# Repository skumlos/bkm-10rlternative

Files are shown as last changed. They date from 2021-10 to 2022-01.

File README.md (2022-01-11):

BKM-10Rlternative, a plug-and-play replacement for the BKM-10R/11R (except for memory card, for now).

Inspired by Aaron Bonhams BKM-10Rduino, which is genious!

Still early, and there's a LOT of components, plus some tweaks might still be needed: 
* Button RC-filters, as I feel that the 10nF should be replaced with 100nF, but needs testing.
* LED current limiting resistors is of course a preference. I used 470 Ohm in my first prototype.
* UART CTS/RTS pins are sorta irrelevant, as they're set static anyways. Removing these would also free
up pins for porting to regular Atmega328P/Arduino Nano 3.0 board.
* The discrete SS pins for each MCP23S17 should be irrelevant when using multiple addresses (which they
are configured as) so removing them in the future, to free up pins would be an idea.

Plans on memory card stuff for firmware updates and such via SD cards, is planned, at least to be researched.

While the unit is modeled after the BKM-11R, the wiring of the serial port is done like the BKM-10R, meaning
it uses a straight through male-male RS232/DE-9 cable, just like the BKM-10R. It is therefore not compatible
with BKM-11R DE-9 -> mini-DIN cables, unless you make your own.

There is a "classic" IR receiver designed into the PCB. It is unused at the moment, and shouldn't be mounted
before the software actually uses it. It was/is meant to be able to replicate some of the BKM-10Rduino 
functionality at some point, to have an all-in-one unit.

(2022) Martin Hejnfelt, martin@hejnfelt.com

https://www.immerhax.com

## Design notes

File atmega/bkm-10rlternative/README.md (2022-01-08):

BKM-10Rlternative code for Atmega328PB MCU

This code is based on the pastebin of the BKM-10R protocol found here: https://pastebin.com/aTUWf33J

For now I have at least one addition to this, namely that the ICC "bank" seems to be more like an "update me" command
if initiated from the remote, or an "you'd better update" if initiated from the monitor. So if the monitor issues
an ICC message, and the remote replies with this, the monitor gives the LED states back.
Thus this is also initiated by the remote when booted, as the monitor *might* be turned on already when the remote
gets power, and it thus needs to have its LED states updated.

Also the "ticks" of the encoders are kinda weird, it's at least not just "how far the encoder has moved", as that
basically makes turning the knobs min -> max take forever (unless the original encoders have *a lot* of PPRs).
I haven't listened in on the original remote, but I've decided that this "fine tuning" or 
"let's turn that sucker" depending on tick number approach seems to work close to the original.

Easiest way to get this going is to install MiniCore in Arduino IDE.

-----------

I have used a couple of libraries to avoid re-inventing the wheel, so here are some attributions:

Yet Another Arduino PcInt Library (LGPL license):
* PinChangeInterruptBoards.h
* YetAnotherPcInt.cpp
* YetAnotherPcInt.h

Full library here: https://github.com/paulo-raca/YetAnotherArduinoPcIntLibrary 

This is used to control the rotary encoders for pin change interrupts. 
The Atmega328PB is not natively supported by this library, so I've patched it in.

MCP23S17 (Unknown license):
* MCP23S17.cpp
* MCP23S17.h

Full library here: https://github.com/n0mjs710/MCP23S17

This is used to speak with the MCP23S17 SPI I/O expanders. Since I used SPI1, I had to patch this in.

-----------

Suggestions, criticism, takedown notices, etc. go to martin@hejnfelt.com. 

(2022) Martin Hejnfelt, https://www.immerhax.com

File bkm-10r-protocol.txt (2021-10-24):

BKM-10R Protocol
Version 1 - May 16, 2016
License: CC0

The BKM-10R is a remote control used for Sony BVM CRT televisions. It is
required to control some CRTs without built in control, such as the BVM-20F1U.

The protocol is vaguely similar to the one used to control Sony VCRs:
ftp://ftp.sgi.com/sgi/video/rld/vidpage/s9pin.html

This document currently only applies to the CONTROL connection, not to the
REMOTE 1 input/output, though it's expected that they are similar.

== Pinout ==

The remote control and CRT are connected with straight through male-male DE9
cable.

Female DB-9, BKM-10R side:
1. GND
2. /TXD
3. RXD
4. GND
5. +5V
6. GND
7. TXD
8. /RXD
9. GND

Since a straight through cable is used, TXD on the remote side is RXD on the
CRT side. +5V is supplied from the CRT to power the remote.

== Protocol ==

Full duplex RS-422, 38400 baud, 8N1 (the Sony VCR protocol uses odd parity, but
that seems not to be the case here). If you only want to control the CRT,
half duplex RS-485 is electrically compatible.

== Bank ==

There are multiple "banks" that can be switched via 3 byte commands:
0x49 0x45 0x4E - "IEN" - encoders
0x49 0x53 0x57 - "ISW" - switches
0x49 0x4C 0x45 - "ILE" - leds
0x49 0x43 0x43 - "ICC" - ??
0x49 0x4d 0x54 - "IMT" - ??

The remote lazily switches banks when needed.

== Keypresses ==

Each keydown sends 0x44, then group, then mask.
0x44 <group> <mask>

The SHIFT key is "just another key" - state is kept on the CRT. Shifted labels
are listed after non-shifted labels.

You must be in the "ISW" bank first.

<group> <mask> - label
0x03 0x01 - SHIFT
0x03 0x02 - OVERSCAN / 16:9
0x03 0x04 - HORIZ SYNC VIEW / SYNC
0x03 0x08 - VERT SYNC VIEW / BLUE ONLY
0x03 0x10 - MONO / R
0x04 0x01 - APT / G
0x04 0x02 - COMB / B
0x04 0x04 - F1 / F3
0x04 0x08 - F2 / F4
0x04 0x10 - SAFE AREA / ADDRESS
0x02 0x40 - UP
0x02 0x80 - DOWN
0x02 0x10 - MENU
0x02 0x20 - ENTER
0x02 0x08 - PHASE MANUAL
0x02 0x04 - CHROMA MANUAL
0x02 0x02 - BRIGHT MANUAL
0x02 0x01 - CONTRAST MANUAL
0x00 0x01 - 0
0x00 0x02 - 1
0x00 0x04 - 2
0x00 0x08 - 3
0x00 0x10 - 4
0x00 0x20 - 5
0x00 0x40 - 6
0x00 0x80 - 7
0x01 0x01 - 8
0x01 0x02 - 9
0x01 0x04 - Del
0x01 0x08 - Ent
0x01 0x10 - POWER (but see below)
0x01 0x20 - DEGAUSS

== POWER ==

You only need to send a POWER keypress to turn on the monitor, but for some
reason the remote does more.

Power sends five 3-byte sequences:
0x49 0x53 0x57 - switch bank
0x44 0x01 0x10 - POWER switch
(1s pause)
0x49 0x43 0x43 - CC bank?
0x49 0x4d 0x54 - MT bank?
0x44 0x33 0x31 - switch?

CRT responds with:
0x49 0x43 0x43 - CC bank?
<full led state report>
0x49 0x4d 0x54 - MT bank?
<full led state report>

== Encoders ==

Dials are rotary encoders that send 3 bytes:
0x44 <encoder id id> <ticks>

Ticks is a two's complement byte indicating how far the dial has turned since
the last message. The remote sends messages about every 100ms when the dial
is turning.

You must be in the "IEN" bank first.

0x03 - PHASE
0x02 - CHROMA
0x01 - BRIGHT
0x00 - CONTRAST

== LEDs ==

LEDs use the same groups and masks as keypresses. Every time the CRT needs to
change the lights, it changes to the LED bank:

0x49 0x4c 0x45

then sends changed switch groups:

0x44 <group> <mask>

where <mask> is all of the active LED masks OR'd together.

== Memory Card ==

Nobody cares.

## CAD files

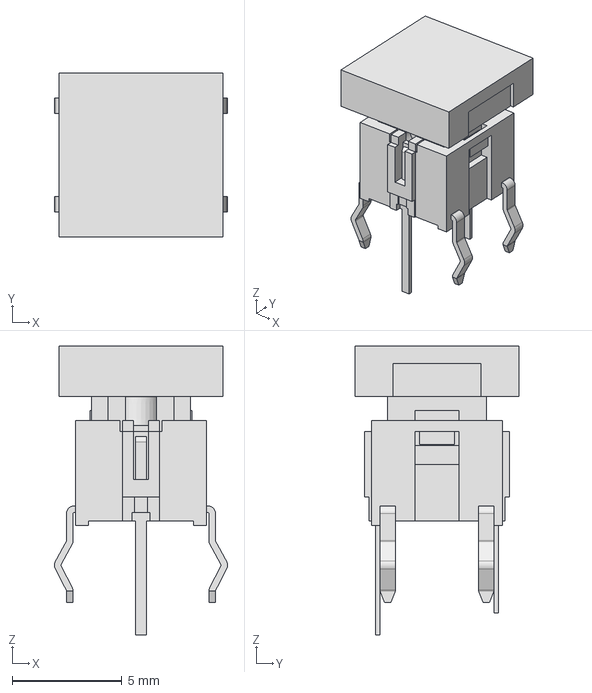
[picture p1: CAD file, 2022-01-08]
TL1240xQ2Jxxx.stp
7.90 x 7.50 x 13.2 mm

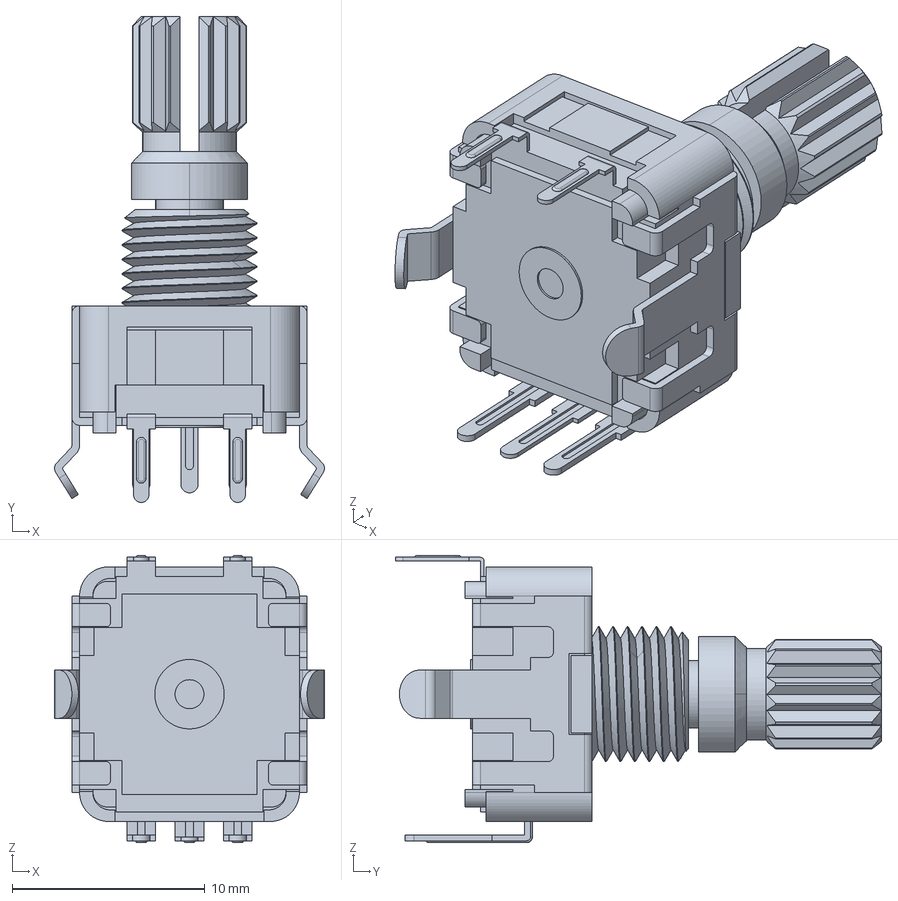
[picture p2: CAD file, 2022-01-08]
pec11r-4x15k-sxxxx.stp
14.0 x 25.2 x 14.9 mm

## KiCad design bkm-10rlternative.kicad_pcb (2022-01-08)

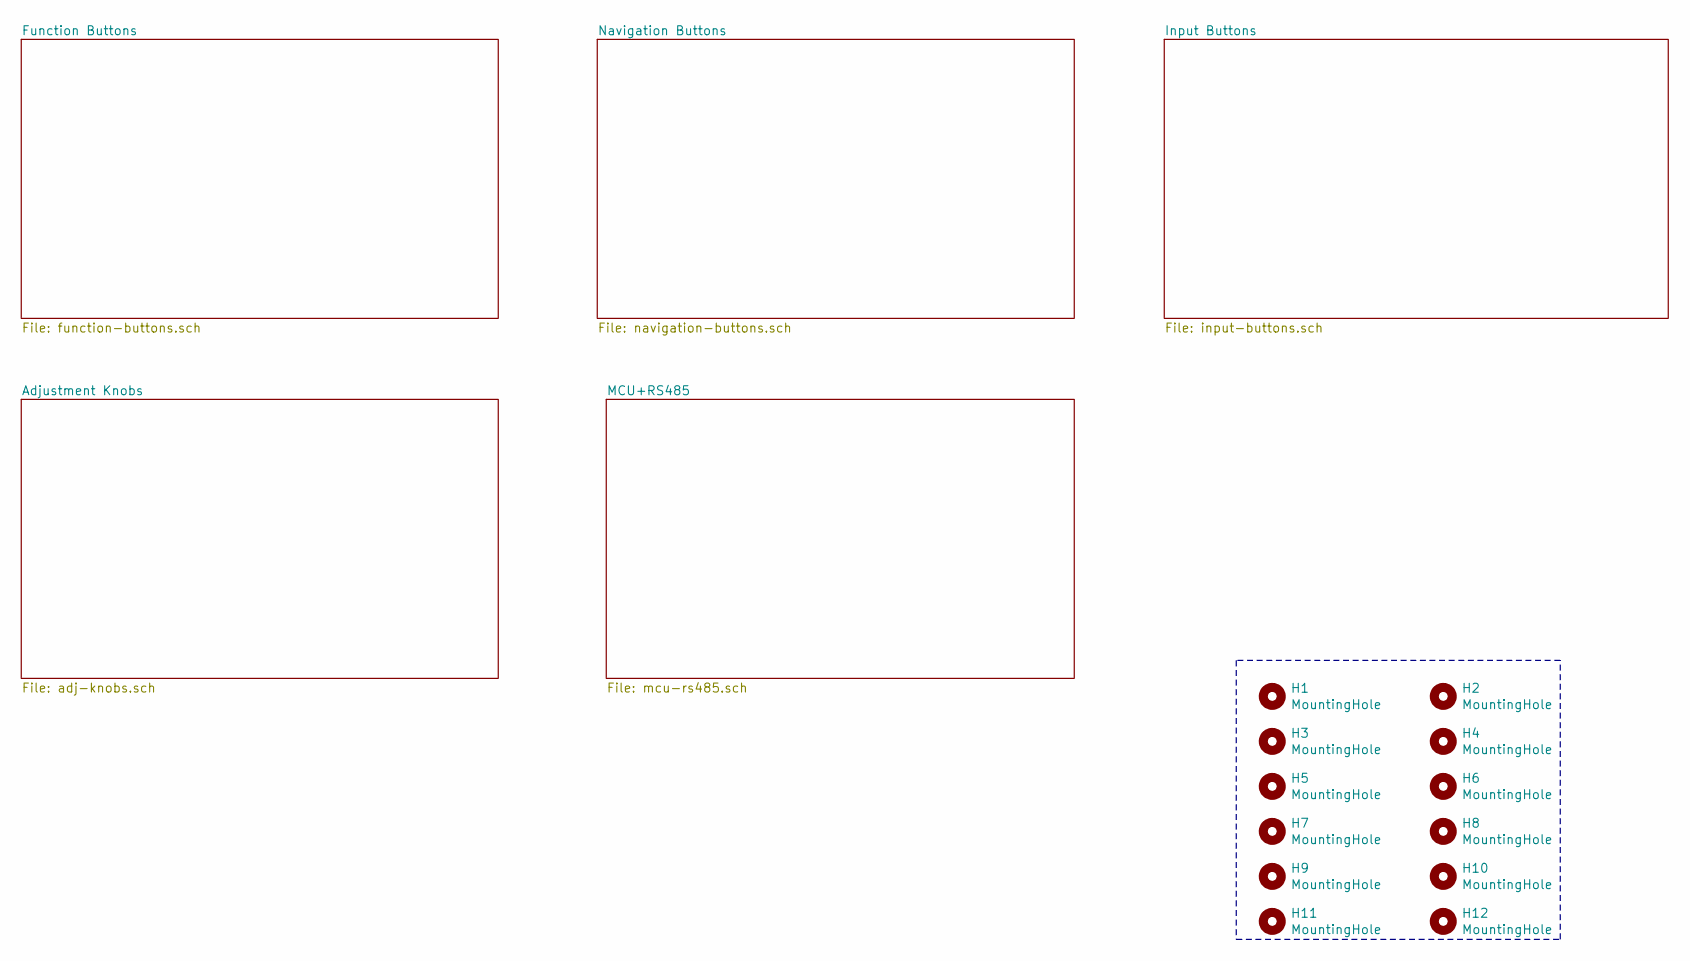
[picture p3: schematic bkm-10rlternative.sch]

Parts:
H1, H2, H3, H4, H5, H6, H7, H8, H9, H10, H11, H12: MountingHole; MountingHole_3.2mm_M3

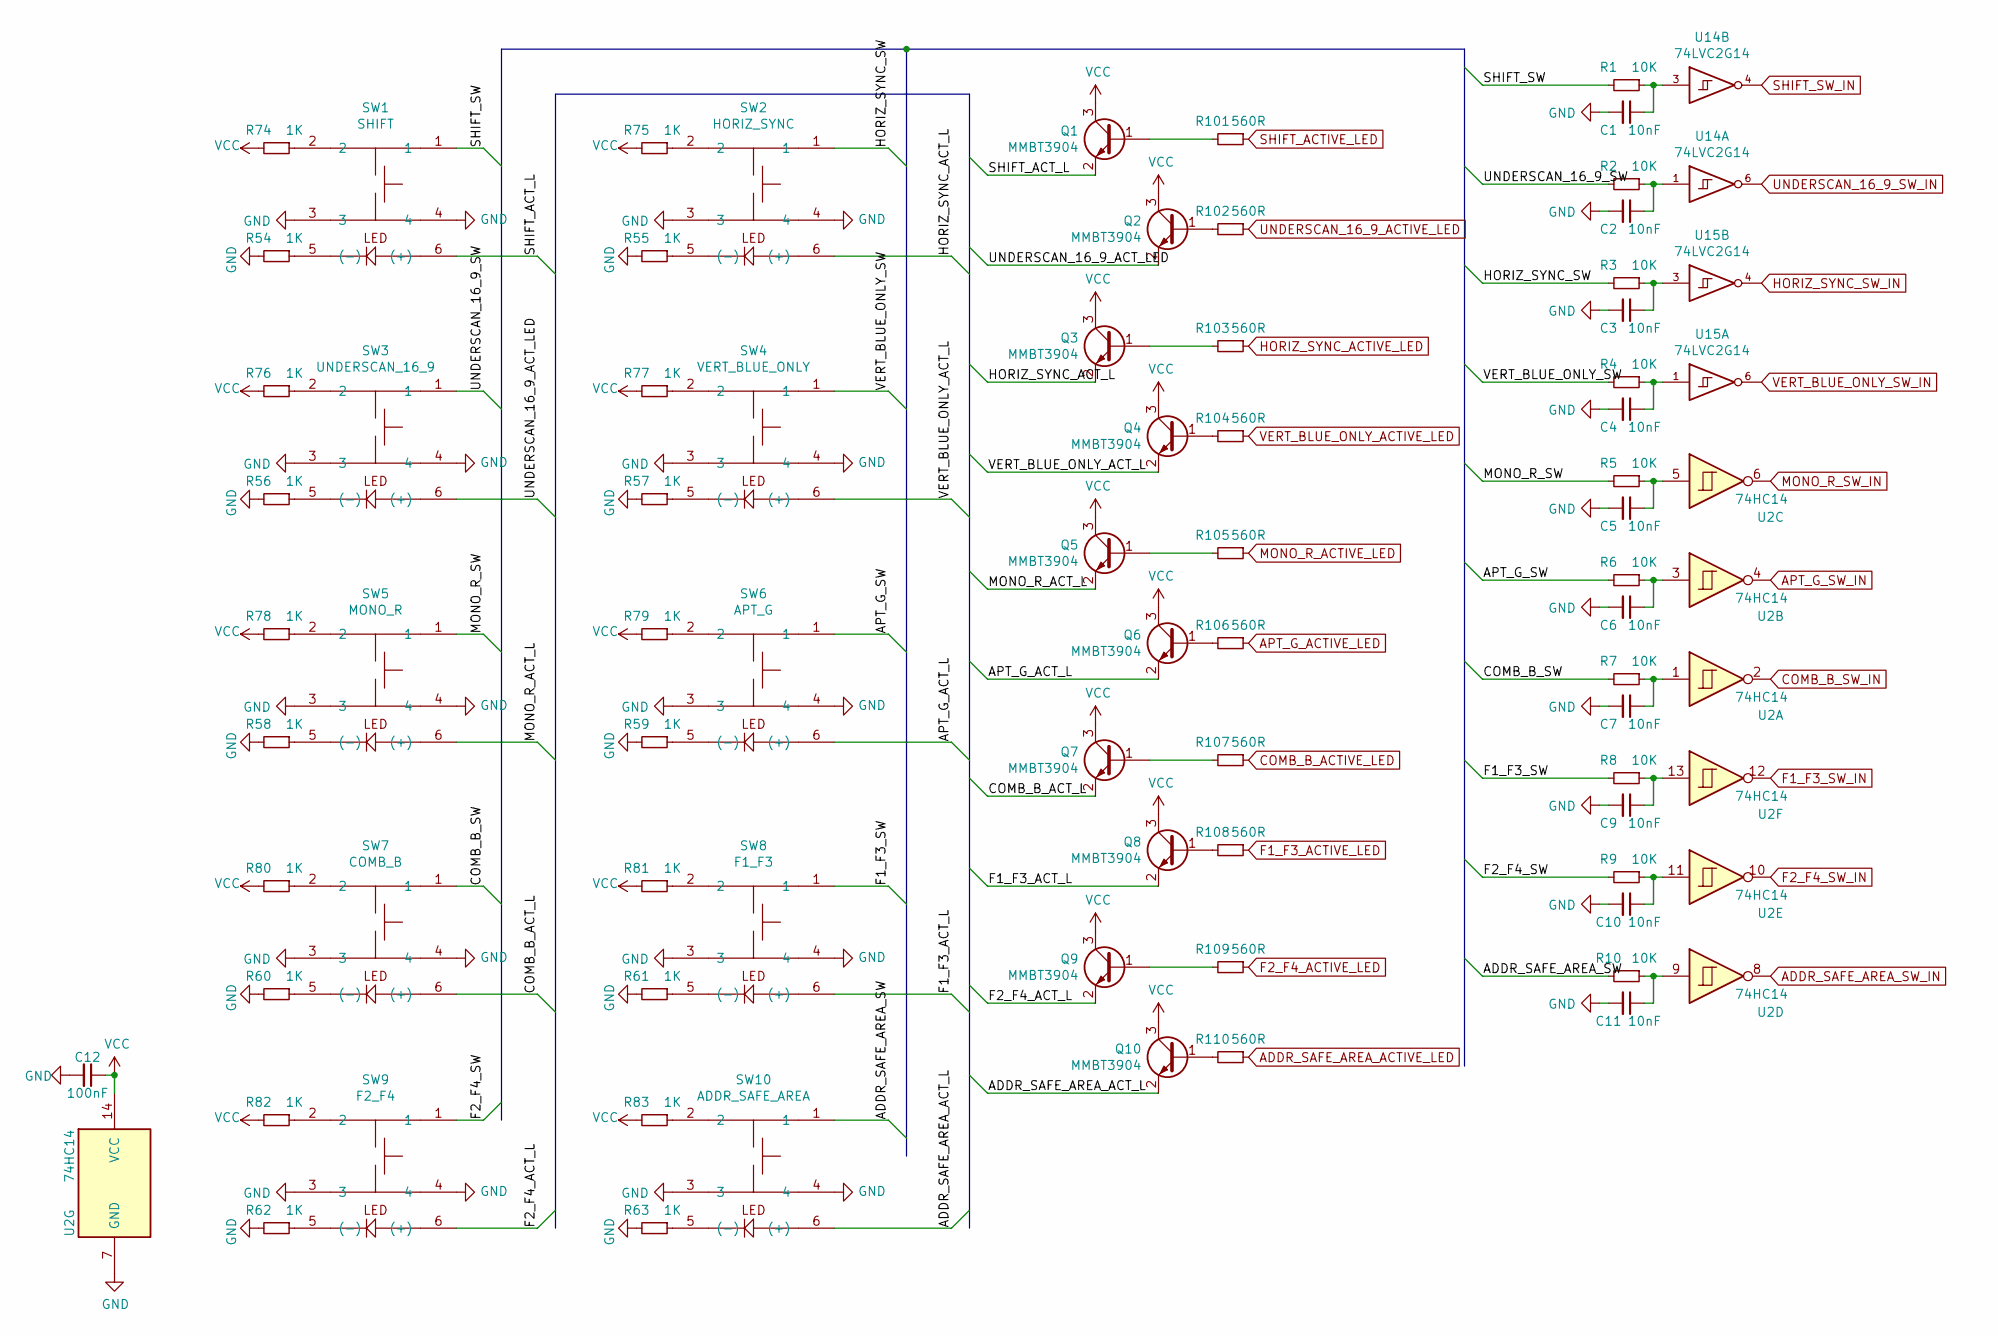
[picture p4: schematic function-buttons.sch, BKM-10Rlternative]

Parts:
C1, C2, C3, C4, C5, C6, C7, C9, C10, C11: 10nF; C_0603_1608Metric_Pad1.08x0.95mm_HandSolder
C12: 100nF; C_0603_1608Metric_Pad1.08x0.95mm_HandSolder
Q1, Q2, Q3, Q4, Q5, Q6, Q7, Q8, Q9, Q10: MMBT3904; SOT-23
R1, R2, R3, R4, R5, R6, R7, R8, R9, R10: 10K; R_0603_1608Metric_Pad0.98x0.95mm_HandSolder
R54, R55, R56, R57, R58, R59, R60, R61, R62, R63, R74, R75, R76, R77, R78, R79, R80, R81, R82, R83: 1K; R_0603_1608Metric_Pad0.98x0.95mm_HandSolder
R101, R102, R103, R104, R105, R106, R107, R108, R109, R110: 560R; R_0603_1608Metric_Pad0.98x0.95mm_HandSolder
SW1: SHIFT; TL-1240
SW2: HORIZ_SYNC; TL-1240
SW3: UNDERSCAN_16_9; TL-1240
SW4: VERT_BLUE_ONLY; TL-1240
SW5: MONO_R; TL-1240
SW6: APT_G; TL-1240
SW7: COMB_B; TL-1240
SW8: F1_F3; TL-1240
SW9: F2_F4; TL-1240
SW10: ADDR_SAFE_AREA; TL-1240
U2: 74HC14; SSOP-14_5.3x6.2mm_P0.65mm
U14, U15: 74LVC2G14; SOT-23-6_Handsoldering

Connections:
/Function Buttons/ADDR_SAFE_AREA_ACT_L: Q10.2 (E), SW10.6 ((+))
/Function Buttons/ADDR_SAFE_AREA_SW: R10.2, SW10.1
/Function Buttons/APT_G_ACT_L: Q6.2 (E), SW6.6 ((+))
/Function Buttons/APT_G_SW: R6.2, SW6.1
/Function Buttons/COMB_B_ACT_L: Q7.2 (E), SW7.6 ((+))
/Function Buttons/COMB_B_SW: R7.2, SW7.1
/Function Buttons/F1_F3_ACT_L: Q8.2 (E), SW8.6 ((+))
/Function Buttons/F1_F3_SW: R8.2, SW8.1
/Function Buttons/F2_F4_ACT_L: Q9.2 (E), SW9.6 ((+))
/Function Buttons/F2_F4_SW: R9.2, SW9.1
/Function Buttons/HORIZ_SYNC_ACT_L: Q3.2 (E), SW2.6 ((+))
/Function Buttons/HORIZ_SYNC_SW: R3.2, SW2.1
/Function Buttons/MONO_R_ACT_L: Q5.2 (E), SW5.6 ((+))
/Function Buttons/MONO_R_SW: R5.2, SW5.1
/Function Buttons/SHIFT_ACT_L: Q1.2 (E), SW1.6 ((+))
/Function Buttons/SHIFT_SW: R1.2, SW1.1
/Function Buttons/UNDERSCAN_16_9_ACT_LED: Q2.2 (E), SW3.6 ((+))
/Function Buttons/UNDERSCAN_16_9_SW: R2.2, SW3.1
/Function Buttons/VERT_BLUE_ONLY_ACT_L: Q4.2 (E), SW4.6 ((+))
/Function Buttons/VERT_BLUE_ONLY_SW: R4.2, SW4.1
ADDR_SAFE_AREA_ACTIVE_LED: R110.1; also elsewhere on the board
ADDR_SAFE_AREA_SW_IN: U2.8; also elsewhere on the board
APT_G_ACTIVE_LED: R106.1; also elsewhere on the board
APT_G_SW_IN: U2.4; also elsewhere on the board
COMB_B_ACTIVE_LED: R107.1; also elsewhere on the board
COMB_B_SW_IN: U2.2; also elsewhere on the board
F1_F3_ACTIVE_LED: R108.1; also elsewhere on the board
F1_F3_SW_IN: U2.12; also elsewhere on the board
F2_F4_ACTIVE_LED: R109.1; also elsewhere on the board
F2_F4_SW_IN: U2.10; also elsewhere on the board
GND: C1.2, C2.2, C3.2, C4.2, C5.2, C6.2, C7.2, C9.2, C10.2, C11.2, C12.2, R54.2, R55.2, R56.2, R57.2, R58.2, R59.2, R60.2, R61.2, R62.2, R63.2, SW1.3, SW1.4, SW2.3, SW2.4, SW3.3, SW3.4, SW4.3, SW4.4, SW5.3, SW5.4, SW6.3, SW6.4, SW7.3, SW7.4, SW8.3, SW8.4, SW9.3, SW9.4, SW10.3, SW10.4, U2.7 (GND), U14.2 (GND), U15.2 (GND); also elsewhere on the board
HORIZ_SYNC_ACTIVE_LED: R103.1; also elsewhere on the board
HORIZ_SYNC_SW_IN: U15.4; also elsewhere on the board
MONO_R_ACTIVE_LED: R105.1; also elsewhere on the board
MONO_R_SW_IN: U2.6; also elsewhere on the board
unnamed: C1.1, R1.1, U14.3
unnamed: C2.1, R2.1, U14.1
unnamed: C3.1, R3.1, U15.3
unnamed: C4.1, R4.1, U15.1
unnamed: C5.1, R5.1, U2.5
unnamed: C6.1, R6.1, U2.3
unnamed: C7.1, R7.1, U2.1
unnamed: C9.1, R8.1, U2.13
unnamed: C10.1, R9.1, U2.11
unnamed: C11.1, R10.1, U2.9
unnamed: Q1.1 (B), R101.2
unnamed: Q2.1 (B), R102.2
unnamed: Q3.1 (B), R103.2
unnamed: Q4.1 (B), R104.2
unnamed: Q5.1 (B), R105.2
unnamed: Q6.1 (B), R106.2
unnamed: Q7.1 (B), R107.2
unnamed: Q8.1 (B), R108.2
unnamed: Q9.1 (B), R109.2
unnamed: Q10.1 (B), R110.2
unnamed: R54.1, SW1.5 ((-))
unnamed: R55.1, SW2.5 ((-))
unnamed: R56.1, SW3.5 ((-))
unnamed: R57.1, SW4.5 ((-))
unnamed: R58.1, SW5.5 ((-))
unnamed: R59.1, SW6.5 ((-))
unnamed: R60.1, SW7.5 ((-))
unnamed: R61.1, SW8.5 ((-))
unnamed: R62.1, SW9.5 ((-))
unnamed: R63.1, SW10.5 ((-))
unnamed: R74.1, SW1.2
unnamed: R75.1, SW2.2
unnamed: R76.1, SW3.2
unnamed: R77.1, SW4.2
unnamed: R78.1, SW5.2
unnamed: R79.1, SW6.2
unnamed: R80.1, SW7.2
unnamed: R81.1, SW8.2
unnamed: R82.1, SW9.2
unnamed: R83.1, SW10.2
SHIFT_ACTIVE_LED: R101.1; also elsewhere on the board
SHIFT_SW_IN: U14.4; also elsewhere on the board
UNDERSCAN_16_9_ACTIVE_LED: R102.1; also elsewhere on the board
UNDERSCAN_16_9_SW_IN: U14.6; also elsewhere on the board
VCC: C12.1, Q1.3 (C), Q2.3 (C), Q3.3 (C), Q4.3 (C), Q5.3 (C), Q6.3 (C), Q7.3 (C), Q8.3 (C), Q9.3 (C), Q10.3 (C), R74.2, R75.2, R76.2, R77.2, R78.2, R79.2, R80.2, R81.2, R82.2, R83.2, U2.14 (VCC), U14.5 (VCC), U15.5 (VCC); also elsewhere on the board
VERT_BLUE_ONLY_ACTIVE_LED: R104.1; also elsewhere on the board
VERT_BLUE_ONLY_SW_IN: U15.6; also elsewhere on the board

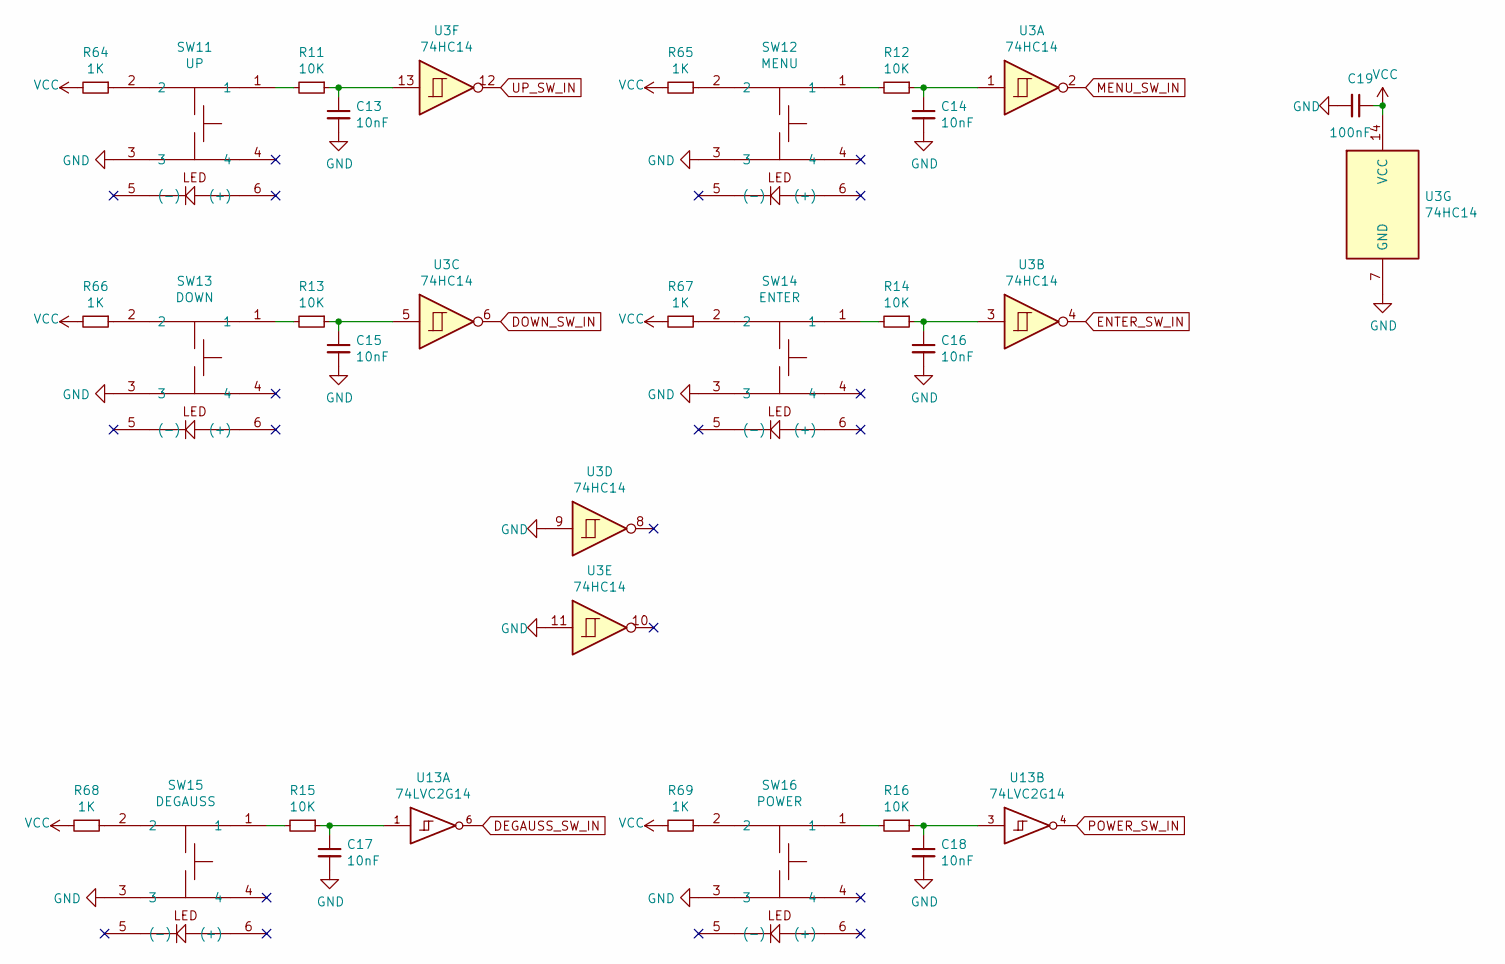
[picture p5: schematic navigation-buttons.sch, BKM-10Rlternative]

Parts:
C13, C14, C15, C16, C17, C18: 10nF; C_0603_1608Metric_Pad1.08x0.95mm_HandSolder
C19: 100nF; C_0603_1608Metric_Pad1.08x0.95mm_HandSolder
R11, R12, R13, R14, R15, R16: 10K; R_0603_1608Metric_Pad0.98x0.95mm_HandSolder
R64, R65, R66, R67, R68, R69: 1K; R_0603_1608Metric_Pad0.98x0.95mm_HandSolder
SW11: UP; TL-1240
SW12: MENU; TL-1240
SW13: DOWN; TL-1240
SW14: ENTER; TL-1240
SW15: DEGAUSS; TL-1240
SW16: POWER; TL-1240
U3: 74HC14; SSOP-14_5.3x6.2mm_P0.65mm
U13: 74LVC2G14; SOT-23-6_Handsoldering

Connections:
DEGAUSS_SW_IN: U13.6; also elsewhere on the board
DOWN_SW_IN: U3.6; also elsewhere on the board
ENTER_SW_IN: U3.4; also elsewhere on the board
GND: C13.2, C14.2, C15.2, C16.2, C17.2, C18.2, C19.2, SW11.3, SW12.3, SW13.3, SW14.3, SW15.3, SW16.3, U3.7 (GND), U3.9, U3.11, U13.2 (GND); also elsewhere on the board
MENU_SW_IN: U3.2; also elsewhere on the board
unnamed: C13.1, R11.1, U3.13
unnamed: C14.1, R12.1, U3.1
unnamed: C15.1, R13.1, U3.5
unnamed: C16.1, R14.1, U3.3
unnamed: C17.1, R15.1, U13.1
unnamed: C18.1, R16.1, U13.3
unnamed: R11.2, SW11.1
unnamed: R12.2, SW12.1
unnamed: R13.2, SW13.1
unnamed: R14.2, SW14.1
unnamed: R15.2, SW15.1
unnamed: R16.2, SW16.1
unnamed: R64.1, SW11.2
unnamed: R65.1, SW12.2
unnamed: R66.1, SW13.2
unnamed: R67.1, SW14.2
unnamed: R68.1, SW15.2
unnamed: R69.1, SW16.2
POWER_SW_IN: U13.4; also elsewhere on the board
UP_SW_IN: U3.12; also elsewhere on the board
VCC: C19.1, R64.2, R65.2, R66.2, R67.2, R68.2, R69.2, U3.14 (VCC), U13.5 (VCC); also elsewhere on the board

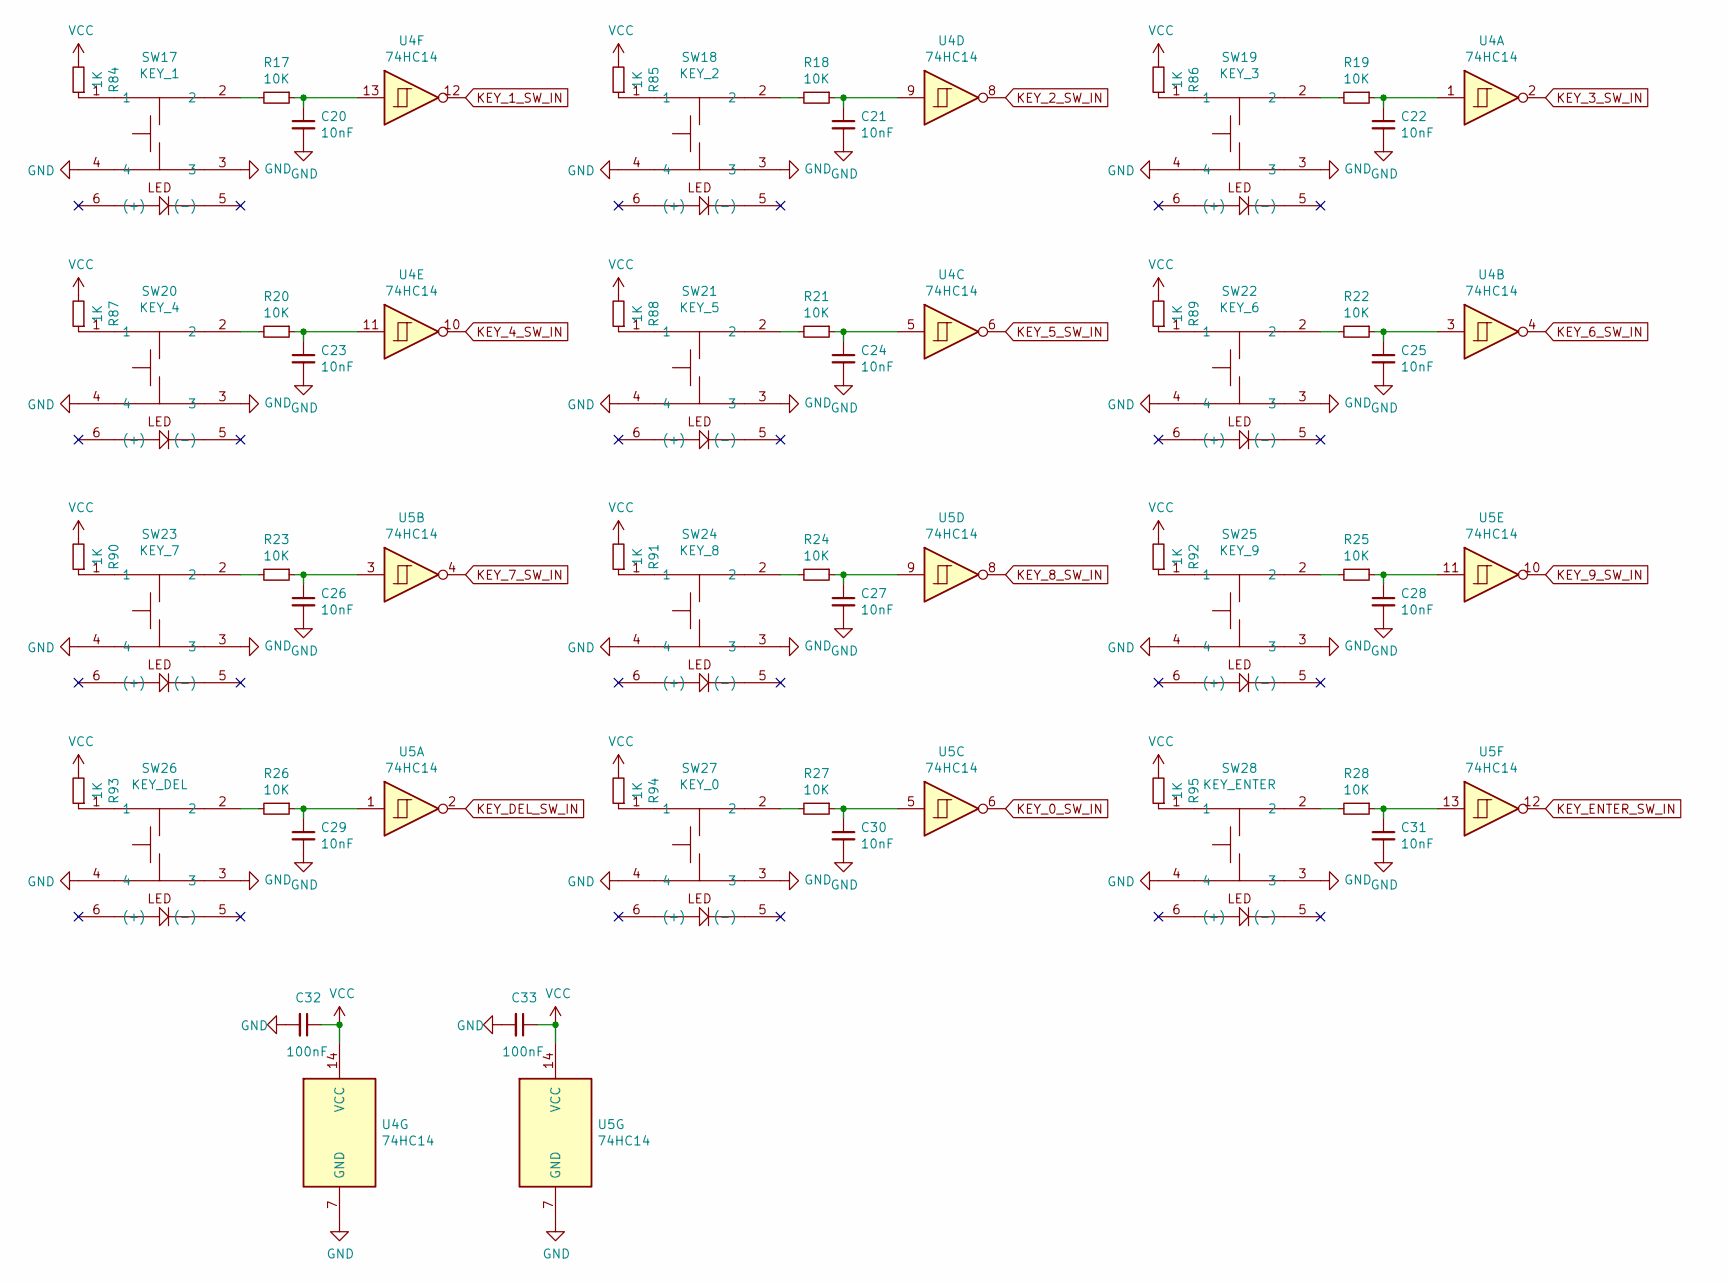
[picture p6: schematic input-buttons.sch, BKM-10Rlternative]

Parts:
C20, C21, C22, C23, C24, C25, C26, C27, C28, C29, C30, C31: 10nF; C_0603_1608Metric_Pad1.08x0.95mm_HandSolder
C32, C33: 100nF; C_0603_1608Metric_Pad1.08x0.95mm_HandSolder
R17, R18, R19, R20, R21, R22, R23, R24, R25, R26, R27, R28: 10K; R_0603_1608Metric_Pad0.98x0.95mm_HandSolder
R84, R85, R86, R87, R88, R89, R90, R91, R92, R93, R94, R95: 1K; R_0603_1608Metric_Pad0.98x0.95mm_HandSolder
SW17: KEY_1; TL-1240
SW18: KEY_2; TL-1240
SW19: KEY_3; TL-1240
SW20: KEY_4; TL-1240
SW21: KEY_5; TL-1240
SW22: KEY_6; TL-1240
SW23: KEY_7; TL-1240
SW24: KEY_8; TL-1240
SW25: KEY_9; TL-1240
SW26: KEY_DEL; TL-1240
SW27: KEY_0; TL-1240
SW28: KEY_ENTER; TL-1240
U4, U5: 74HC14; SSOP-14_5.3x6.2mm_P0.65mm

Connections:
GND: C20.2, C21.2, C22.2, C23.2, C24.2, C25.2, C26.2, C27.2, C28.2, C29.2, C30.2, C31.2, C32.2, C33.2, SW17.3, SW17.4, SW18.3, SW18.4, SW19.3, SW19.4, SW20.3, SW20.4, SW21.3, SW21.4, SW22.3, SW22.4, SW23.3, SW23.4, SW24.3, SW24.4, SW25.3, SW25.4, SW26.3, SW26.4, SW27.3, SW27.4, SW28.3, SW28.4, U4.7 (GND), U5.7 (GND); also elsewhere on the board
KEY_0_SW_IN: U5.6; also elsewhere on the board
KEY_1_SW_IN: U4.12; also elsewhere on the board
KEY_2_SW_IN: U4.8; also elsewhere on the board
KEY_3_SW_IN: U4.2; also elsewhere on the board
KEY_4_SW_IN: U4.10; also elsewhere on the board
KEY_5_SW_IN: U4.6; also elsewhere on the board
KEY_6_SW_IN: U4.4; also elsewhere on the board
KEY_7_SW_IN: U5.4; also elsewhere on the board
KEY_8_SW_IN: U5.8; also elsewhere on the board
KEY_9_SW_IN: U5.10; also elsewhere on the board
KEY_DEL_SW_IN: U5.2; also elsewhere on the board
KEY_ENTER_SW_IN: U5.12; also elsewhere on the board
unnamed: C20.1, R17.1, U4.13
unnamed: C21.1, R18.1, U4.9
unnamed: C22.1, R19.1, U4.1
unnamed: C23.1, R20.1, U4.11
unnamed: C24.1, R21.1, U4.5
unnamed: C25.1, R22.1, U4.3
unnamed: C26.1, R23.1, U5.3
unnamed: C27.1, R24.1, U5.9
unnamed: C28.1, R25.1, U5.11
unnamed: C29.1, R26.1, U5.1
unnamed: C30.1, R27.1, U5.5
unnamed: C31.1, R28.1, U5.13
unnamed: R17.2, SW17.2
unnamed: R18.2, SW18.2
unnamed: R19.2, SW19.2
unnamed: R20.2, SW20.2
unnamed: R21.2, SW21.2
unnamed: R22.2, SW22.2
unnamed: R23.2, SW23.2
unnamed: R24.2, SW24.2
unnamed: R25.2, SW25.2
unnamed: R26.2, SW26.2
unnamed: R27.2, SW27.2
unnamed: R28.2, SW28.2
unnamed: R84.1, SW17.1
unnamed: R85.1, SW18.1
unnamed: R86.1, SW19.1
unnamed: R87.1, SW20.1
unnamed: R88.1, SW21.1
unnamed: R89.1, SW22.1
unnamed: R90.1, SW23.1
unnamed: R91.1, SW24.1
unnamed: R92.1, SW25.1
unnamed: R93.1, SW26.1
unnamed: R94.1, SW27.1
unnamed: R95.1, SW28.1
VCC: C32.1, C33.1, R84.2, R85.2, R86.2, R87.2, R88.2, R89.2, R90.2, R91.2, R92.2, R93.2, R94.2, R95.2, U4.14 (VCC), U5.14 (VCC); also elsewhere on the board

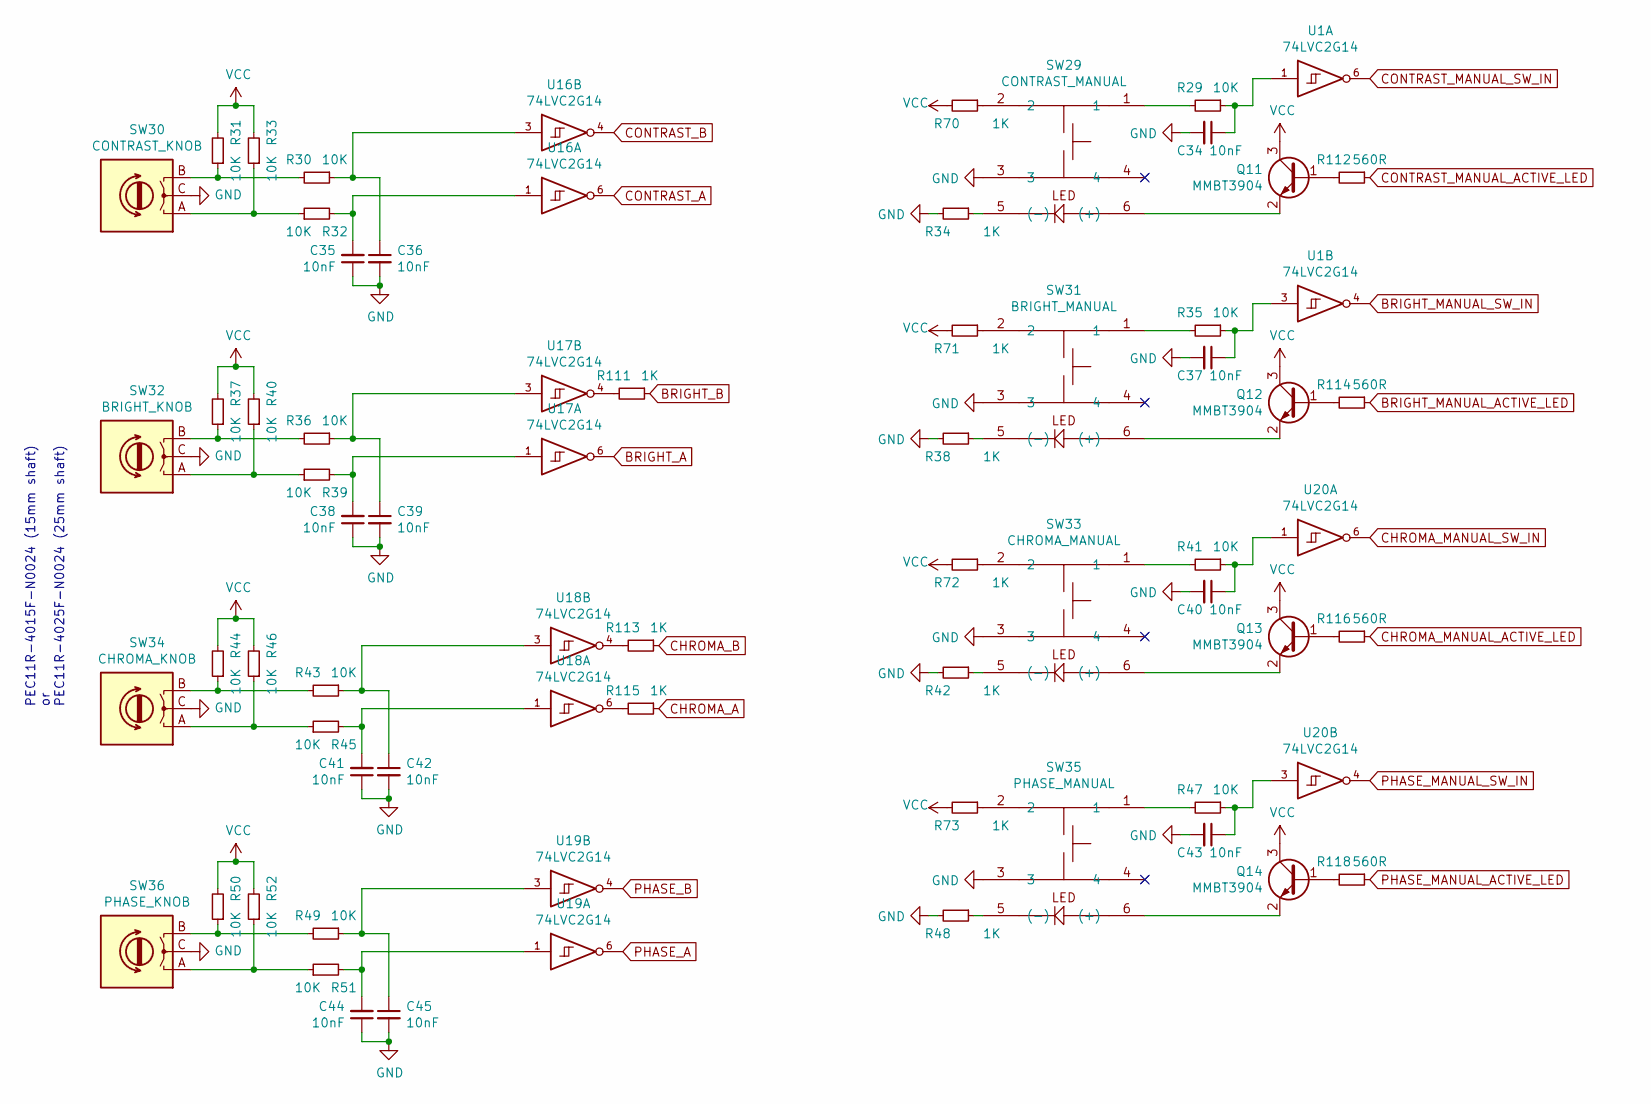
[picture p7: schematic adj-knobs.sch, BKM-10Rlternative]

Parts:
C34, C35, C36, C37, C38, C39, C40, C41, C42, C43, C44, C45: 10nF; C_0603_1608Metric_Pad1.08x0.95mm_HandSolder
Q11, Q12, Q13, Q14: MMBT3904; SOT-23
R29, R30, R31, R32, R33, R35, R36, R37, R39, R40, R41, R43, R44, R45, R46, R47, R49, R50, R51, R52: 10K; R_0603_1608Metric_Pad0.98x0.95mm_HandSolder
R34, R38, R42, R48, R70, R71, R72, R73, R111, R113, R115: 1K; R_0603_1608Metric_Pad0.98x0.95mm_HandSolder
R112, R114, R116, R118: 560R; R_0603_1608Metric_Pad0.98x0.95mm_HandSolder
SW29: CONTRAST_MANUAL; TL-1240
SW30: CONTRAST_KNOB; RotaryEncoder_Alps_EC11E_Vertical_H20mm
SW31: BRIGHT_MANUAL; TL-1240
SW32: BRIGHT_KNOB; RotaryEncoder_Alps_EC11E_Vertical_H20mm
SW33: CHROMA_MANUAL; TL-1240
SW34: CHROMA_KNOB; RotaryEncoder_Alps_EC11E_Vertical_H20mm
SW35: PHASE_MANUAL; TL-1240
SW36: PHASE_KNOB; RotaryEncoder_Alps_EC11E_Vertical_H20mm
U1, U16, U17, U18, U19, U20: 74LVC2G14; SOT-23-6_Handsoldering

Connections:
BRIGHT_A: U17.6; also elsewhere on the board
BRIGHT_B: R111.1; also elsewhere on the board
BRIGHT_MANUAL_ACTIVE_LED: R114.1; also elsewhere on the board
BRIGHT_MANUAL_SW_IN: U1.4; also elsewhere on the board
CHROMA_A: R115.1; also elsewhere on the board
CHROMA_B: R113.1; also elsewhere on the board
CHROMA_MANUAL_ACTIVE_LED: R116.1; also elsewhere on the board
CHROMA_MANUAL_SW_IN: U20.6; also elsewhere on the board
CONTRAST_A: U16.6; also elsewhere on the board
CONTRAST_B: U16.4; also elsewhere on the board
CONTRAST_MANUAL_ACTIVE_LED: R112.1; also elsewhere on the board
CONTRAST_MANUAL_SW_IN: U1.6; also elsewhere on the board
GND: C34.2, C35.1, C36.2, C37.2, C38.1, C39.2, C40.2, C41.1, C42.2, C43.2, C44.1, C45.2, R34.2, R38.2, R42.2, R48.2, SW29.3, SW30.C, SW31.3, SW32.C, SW33.3, SW34.C, SW35.3, SW36.C, U1.2 (GND), U16.2 (GND), U17.2 (GND), U18.2 (GND), U19.2 (GND), U20.2 (GND); also elsewhere on the board
unnamed: C34.1, R29.1, U1.1
unnamed: C35.2, R32.2, U16.1
unnamed: C36.1, R30.1, U16.3
unnamed: C37.1, R35.1, U1.3
unnamed: C38.2, R39.2, U17.1
unnamed: C39.1, R36.1, U17.3
unnamed: C40.1, R41.1, U20.1
unnamed: C41.2, R45.2, U18.1
unnamed: C42.1, R43.1, U18.3
unnamed: C43.1, R47.1, U20.3
unnamed: C44.2, R51.2, U19.1
unnamed: C45.1, R49.1, U19.3
unnamed: Q11.1 (B), R112.2
unnamed: Q11.2 (E), SW29.6 ((+))
unnamed: Q12.1 (B), R114.2
unnamed: Q12.2 (E), SW31.6 ((+))
unnamed: Q13.1 (B), R116.2
unnamed: Q13.2 (E), SW33.6 ((+))
unnamed: Q14.1 (B), R118.2
unnamed: Q14.2 (E), SW35.6 ((+))
unnamed: R29.2, SW29.1
unnamed: R30.2, R31.1, SW30.B
unnamed: R32.1, R33.1, SW30.A
unnamed: R34.1, SW29.5 ((-))
unnamed: R35.2, SW31.1
unnamed: R36.2, R37.1, SW32.B
unnamed: R38.1, SW31.5 ((-))
unnamed: R39.1, R40.1, SW32.A
unnamed: R41.2, SW33.1
unnamed: R42.1, SW33.5 ((-))
unnamed: R43.2, R44.1, SW34.B
unnamed: R45.1, R46.1, SW34.A
unnamed: R47.2, SW35.1
unnamed: R48.1, SW35.5 ((-))
unnamed: R49.2, R50.1, SW36.B
unnamed: R51.1, R52.1, SW36.A
unnamed: R70.1, SW29.2
unnamed: R71.1, SW31.2
unnamed: R72.1, SW33.2
unnamed: R73.1, SW35.2
unnamed: R111.2, U17.4
unnamed: R113.2, U18.4
unnamed: R115.2, U18.6
PHASE_A: U19.6; also elsewhere on the board
PHASE_B: U19.4; also elsewhere on the board
PHASE_MANUAL_ACTIVE_LED: R118.1; also elsewhere on the board
PHASE_MANUAL_SW_IN: U20.4; also elsewhere on the board
VCC: Q11.3 (C), Q12.3 (C), Q13.3 (C), Q14.3 (C), R31.2, R33.2, R37.2, R40.2, R44.2, R46.2, R50.2, R52.2, R70.2, R71.2, R72.2, R73.2, U1.5 (VCC), U16.5 (VCC), U17.5 (VCC), U18.5 (VCC), U19.5 (VCC), U20.5 (VCC); also elsewhere on the board

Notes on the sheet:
PEC11R-4015F-N0024 (15mm shaft) or PEC11R-4025F-N0024 (25mm shaft)

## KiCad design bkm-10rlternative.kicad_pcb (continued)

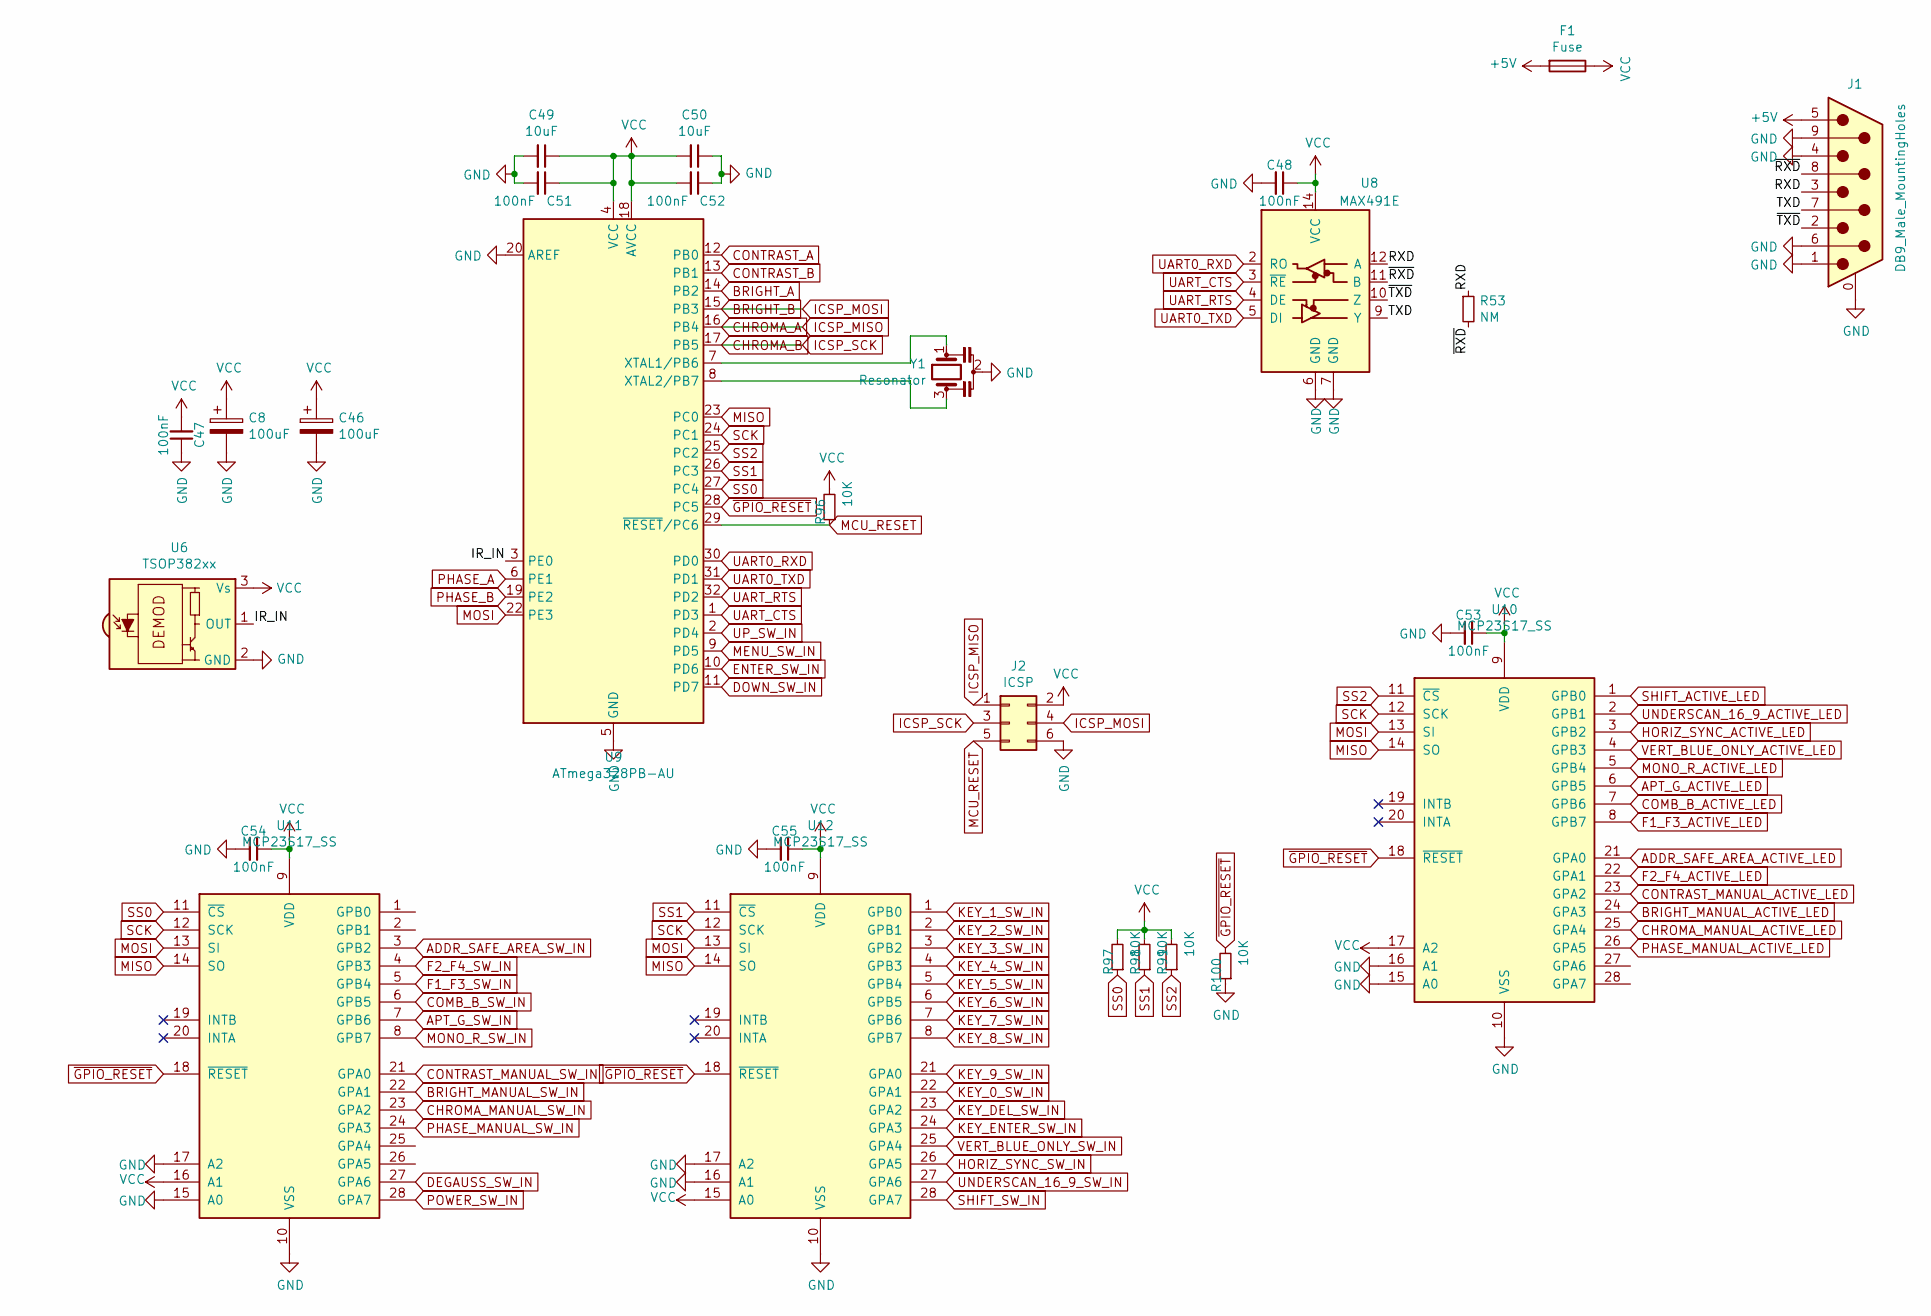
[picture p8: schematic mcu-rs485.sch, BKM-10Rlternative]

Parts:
C8, C46: 100uF; CP_Elec_6.3x5.4
C47, C48, C51, C52, C53, C54, C55: 100nF; C_0603_1608Metric_Pad1.08x0.95mm_HandSolder
C49, C50: 10uF; C_0805_2012Metric_Pad1.18x1.45mm_HandSolder
F1: Fuse; Fuse_1206_3216Metric_Pad1.42x1.75mm_HandSolder
J1: DB9_Male_MountingHoles; DSUB-9_Female_Horizontal_P2.77x2.84mm_EdgePinOffset7.70mm_H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
J2: ICSP; PinHeader_2x03_P2.54mm_Vertical
R53: NM; R_0603_1608Metric_Pad0.98x0.95mm_HandSolder
R96, R97, R98, R99, R100: 10K; R_0603_1608Metric_Pad0.98x0.95mm_HandSolder
U6: TSOP382xx; Vishay_MINICAST-3Pin
U8: MAX491E; SOIC-14_3.9x8.7mm_P1.27mm
U9: ATmega328PB-AU; TQFP-32_7x7mm_P0.8mm
U10, U11, U12: MCP23S17_SS; SSOP-28_5.3x10.2mm_P0.65mm
Y1: Resonator; Resonator_SMD_muRata_CSTxExxV-3Pin_3.0x1.1mm_HandSoldering

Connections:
+5V: F1.2, J1.5
/MCU+RS485/IR_IN: U6.1 (OUT), U9.3 (PE0)
/MCU+RS485/RXD: J1.3, R53.1, U8.12 (A)
/MCU+RS485/TXD: J1.7, U8.9 (Y)
/MCU+RS485/~RXD: J1.8, R53.2, U8.11 (B)
/MCU+RS485/~TXD: J1.2, U8.10 (Z)
ADDR_SAFE_AREA_ACTIVE_LED: U10.21 (GPA0); also elsewhere on the board
ADDR_SAFE_AREA_SW_IN: U11.3 (GPB2); also elsewhere on the board
APT_G_ACTIVE_LED: U10.6 (GPB5); also elsewhere on the board
APT_G_SW_IN: U11.7 (GPB6); also elsewhere on the board
BRIGHT_A: U9.14 (PB2); also elsewhere on the board
BRIGHT_B: J2.4, U9.15 (PB3); also elsewhere on the board
BRIGHT_MANUAL_ACTIVE_LED: U10.24 (GPA3); also elsewhere on the board
BRIGHT_MANUAL_SW_IN: U11.22 (GPA1); also elsewhere on the board
CHROMA_A: J2.1, U9.16 (PB4); also elsewhere on the board
CHROMA_B: J2.3, U9.17 (PB5); also elsewhere on the board
CHROMA_MANUAL_ACTIVE_LED: U10.25 (GPA4); also elsewhere on the board
CHROMA_MANUAL_SW_IN: U11.23 (GPA2); also elsewhere on the board
COMB_B_ACTIVE_LED: U10.7 (GPB6); also elsewhere on the board
COMB_B_SW_IN: U11.6 (GPB5); also elsewhere on the board
CONTRAST_A: U9.12 (PB0); also elsewhere on the board
CONTRAST_B: U9.13 (PB1); also elsewhere on the board
CONTRAST_MANUAL_ACTIVE_LED: U10.23 (GPA2); also elsewhere on the board
CONTRAST_MANUAL_SW_IN: U11.21 (GPA0); also elsewhere on the board
DEGAUSS_SW_IN: U11.27 (GPA6); also elsewhere on the board
DOWN_SW_IN: U9.11 (PD7); also elsewhere on the board
ENTER_SW_IN: U9.10 (PD6); also elsewhere on the board
F1_F3_ACTIVE_LED: U10.8 (GPB7); also elsewhere on the board
F1_F3_SW_IN: U11.5 (GPB4); also elsewhere on the board
F2_F4_ACTIVE_LED: U10.22 (GPA1); also elsewhere on the board
F2_F4_SW_IN: U11.4 (GPB3); also elsewhere on the board
GND: C8.2, C46.2, C47.1, C48.2, C49.2, C50.1, C51.2, C52.1, C53.2, C54.2, C55.2, J1.0 (PAD), J1.1, J1.4, J1.6, J1.9, J2.6, R100.1, U6.2 (GND), U8.6 (GND), U8.7 (GND), U9.5 (GND), U9.20 (AREF), U9.21 (GND), U10.10 (VSS), U10.15 (A0), U10.16 (A1), U11.10 (VSS), U11.15 (A0), U11.17 (A2), U12.10 (VSS), U12.16 (A1), U12.17 (A2), Y1.2; also elsewhere on the board
HORIZ_SYNC_ACTIVE_LED: U10.3 (GPB2); also elsewhere on the board
HORIZ_SYNC_SW_IN: U12.26 (GPA5); also elsewhere on the board
KEY_0_SW_IN: U12.22 (GPA1); also elsewhere on the board
KEY_1_SW_IN: U12.1 (GPB0); also elsewhere on the board
KEY_2_SW_IN: U12.2 (GPB1); also elsewhere on the board
KEY_3_SW_IN: U12.3 (GPB2); also elsewhere on the board
KEY_4_SW_IN: U12.4 (GPB3); also elsewhere on the board
KEY_5_SW_IN: U12.5 (GPB4); also elsewhere on the board
KEY_6_SW_IN: U12.6 (GPB5); also elsewhere on the board
KEY_7_SW_IN: U12.7 (GPB6); also elsewhere on the board
KEY_8_SW_IN: U12.8 (GPB7); also elsewhere on the board
KEY_9_SW_IN: U12.21 (GPA0); also elsewhere on the board
KEY_DEL_SW_IN: U12.23 (GPA2); also elsewhere on the board
KEY_ENTER_SW_IN: U12.24 (GPA3); also elsewhere on the board
MCU_RESET: J2.5, R96.1, U9.29 (~RESET~/PC6)
MENU_SW_IN: U9.9 (PD5); also elsewhere on the board
MISO: U9.23 (PC0), U10.14 (SO), U11.14 (SO), U12.14 (SO)
MONO_R_ACTIVE_LED: U10.5 (GPB4); also elsewhere on the board
MONO_R_SW_IN: U11.8 (GPB7); also elsewhere on the board
MOSI: U9.22 (PE3), U10.13 (SI), U11.13 (SI), U12.13 (SI)
unnamed: U9.7 (XTAL1/PB6), Y1.1
unnamed: U9.8 (XTAL2/PB7), Y1.3
PHASE_A: U9.6 (PE1); also elsewhere on the board
PHASE_B: U9.19 (PE2); also elsewhere on the board
PHASE_MANUAL_ACTIVE_LED: U10.26 (GPA5); also elsewhere on the board
PHASE_MANUAL_SW_IN: U11.24 (GPA3); also elsewhere on the board
POWER_SW_IN: U11.28 (GPA7); also elsewhere on the board
SCK: U9.24 (PC1), U10.12 (SCK), U11.12 (SCK), U12.12 (SCK)
SHIFT_ACTIVE_LED: U10.1 (GPB0); also elsewhere on the board
SHIFT_SW_IN: U12.28 (GPA7); also elsewhere on the board
SS0: R97.1, U9.27 (PC4), U11.11 (~CS~)
SS1: R98.1, U9.26 (PC3), U12.11 (~CS~)
SS2: R99.1, U9.25 (PC2), U10.11 (~CS~)
UART0_RXD: U8.2 (RO), U9.30 (PD0)
UART0_TXD: U8.5 (DI), U9.31 (PD1)
UART_CTS: U8.3 (~RE), U9.1 (PD3)
UART_RTS: U8.4 (DE), U9.32 (PD2)
UNDERSCAN_16_9_ACTIVE_LED: U10.2 (GPB1); also elsewhere on the board
UNDERSCAN_16_9_SW_IN: U12.27 (GPA6); also elsewhere on the board
UP_SW_IN: U9.2 (PD4); also elsewhere on the board
VCC: C8.1, C46.1, C47.2, C48.1, C49.1, C50.2, C51.1, C52.2, C53.1, C54.1, C55.1, F1.1, J2.2, R96.2, R97.2, R98.2, R99.2, U6.3 (Vs), U8.14 (VCC), U9.4 (VCC), U9.18 (AVCC), U10.9 (VDD), U10.17 (A2), U11.9 (VDD), U11.16 (A1), U12.9 (VDD), U12.15 (A0); also elsewhere on the board
VERT_BLUE_ONLY_ACTIVE_LED: U10.4 (GPB3); also elsewhere on the board
VERT_BLUE_ONLY_SW_IN: U12.25 (GPA4); also elsewhere on the board
~GPIO_RESET: R100.2, U9.28 (PC5), U10.18 (~RESET~), U11.18 (~RESET~), U12.18 (~RESET~)

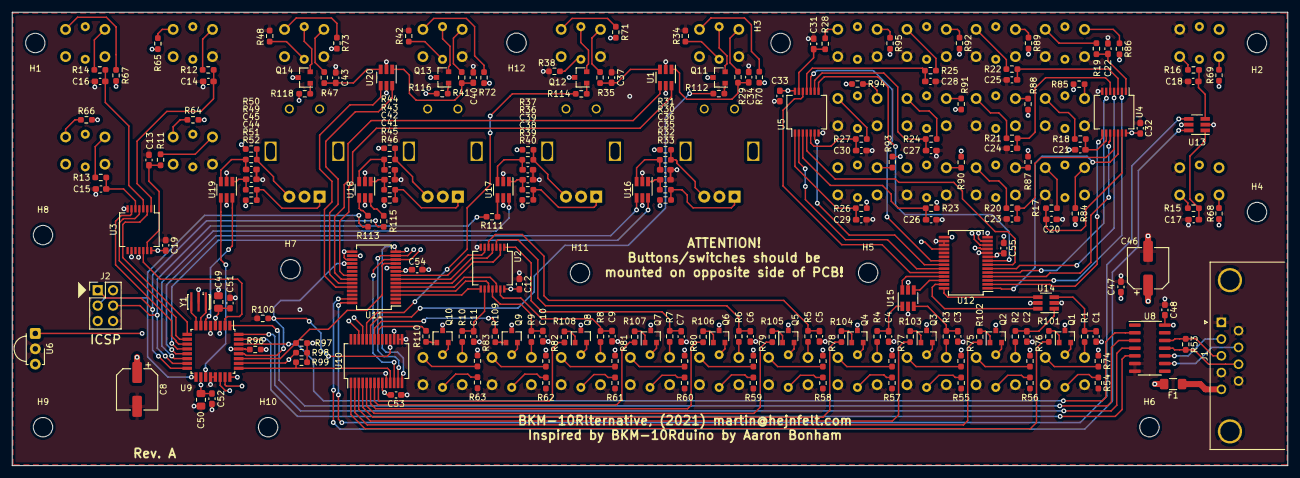
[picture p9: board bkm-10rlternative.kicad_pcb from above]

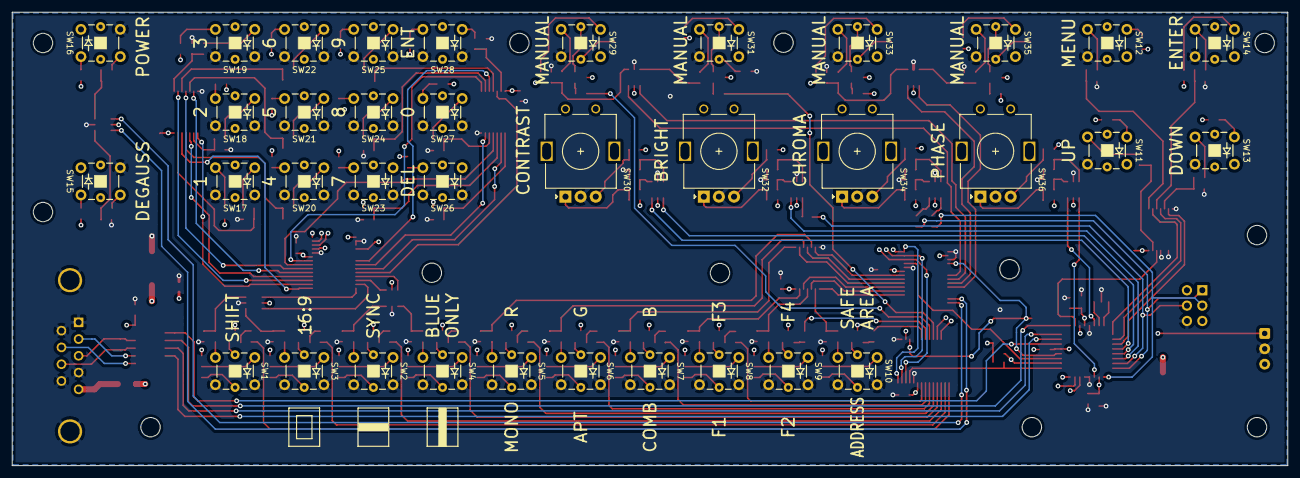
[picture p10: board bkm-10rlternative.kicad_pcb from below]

Board: 4 copper layers, 210.8 x 74.9 mm, 257 parts (36 on the bottom side), 233 nets.

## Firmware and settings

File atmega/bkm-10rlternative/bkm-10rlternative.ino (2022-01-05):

#include "MCP23S17.h"
#include "YetAnotherPcInt.h"
#include "ButtonDefs.h"

// Direct IOs
#define GPIO_RESET        (A5)

#define CONTRAST_A        (8)
#define CONTRAST_B        (9)
#define BRIGHT_A          (10)
#define BRIGHT_B          (11)
#define CHROMA_A          (12)
#define CHROMA_B          (13)
#define PHASE_A           (24)
#define PHASE_B           (25)

#define U11_SS            (A4)
#define U12_SS            (A3)
#define U10_SS            (A2)
#define UART_RTS          (PD2)
#define UART_CTS          (PD3)

#define MENU_IN           (PD5)
#define ENTER_IN          (PD6)
#define UP_IN             (PD4)
#define DOWN_IN           (PD7)

// U11
#define CONTRAST_MANUAL (0x0001)
#define BRIGHT_MANUAL   (0x0002)
#define CHROMA_MANUAL   (0x0004)
#define PHASE_MANUAL    (0x0008)
#define DEGAUSS         (0x0040)
#define POWER           (0x0080)
#define ADDR_SAFE_AREA  (0x0400)
#define F2_F4           (0x0800)
#define F1_F3           (0x1000)
#define COMB_B          (0x2000)
#define APT_G           (0x4000)
#define MONO_R          (0x8000)

// U12
#define KEY9            (0x0001)
#define KEY0            (0x0002)
#define KEY_DEL         (0x0004)
#define KEY_ENTER       (0x0008)
#define VERT_BLUE_ONLY  (0x0010)
#define HORIZ_SYNC      (0x0020)
#define UNDERSCAN_16_9  (0x0040)
#define SHIFT           (0x0080)
#define KEY1            (0x0100)
#define KEY2            (0x0200)
#define KEY3            (0x0400)
#define KEY4            (0x0800)
#define KEY5            (0x1000)
#define KEY6            (0x2000)
#define KEY7            (0x4000)
#define KEY8            (0x8000)

// U10
#define LED_ADDR_SAFE_AREA  (0x0001)
#define LED_F2_F4           (0x0002)
#define LED_CONTRAST_MANUAL (0x0004)
#define LED_BRIGHT_MANUAL   (0x0008)
#define LED_CHROMA_MANUAL   (0x0010)
#define LED_PHASE_MANUAL    (0x0020)
#define GPIO_U10_UNUSED_1   (0x0040)
#define GPIO_U10_UNUSED_2   (0x0080)
#define LED_SHIFT           (0x0100)
#define LED_UNDERSCAN_16_9  (0x0200)
#define LED_HORIZ_SYNC      (0x0400)
#define LED_VERT_BLUE_ONLY  (0x0800)
#define LED_MONO_R          (0x1000)
#define LED_APT_G           (0x2000)
#define LED_COMB_B          (0x4000)
#define LED_F1_F3           (0x8000)

MCP mcp23s17_u10(4, U10_SS); // LEDS
MCP mcp23s17_u11(2, U11_SS);
MCP mcp23s17_u12(1, U12_SS);

enum CurrentBank {
  CB_INIT,
  CB_SWITCHES,
  CB_LEDS,
  CB_ENCODERS,
  CB_CC,
  CB_MT,
};

#define ENCODER_UPDATE_DELTA_MS (100)

CurrentBank currentBank = CB_INIT;

const uint8_t KEY         = 0x44;
const uint8_t BANK        = 0x49;

const uint8_t BANK_ENCODER[]  = { 0x45, 0x4E }; // IEN - Encoders
const uint8_t BANK_SWITCH[]   = { 0x53, 0x57 }; // ISW - Switches
const uint8_t BANK_LED[]      = { 0x4C, 0x45 }; // ILE - LEDS
const uint8_t BANK_CC[]       = { 0x43, 0x43 }; // ICC - Unknown
const uint8_t BANK_MT[]       = { 0x4D, 0x54 }; // IMT - Unknown

const uint8_t ENCODER_PHASE     = 0x03;
const uint8_t ENCODER_CHROMA    = 0x02;
const uint8_t ENCODER_BRIGHT    = 0x01;
const uint8_t ENCODER_CONTRAST  = 0x00;

const uint8_t POWER_ON[] = {KEY,0x33,0x31};

int U11;
int U12;
int prev_U11;
int prev_U12;

uint8_t portD = 0;
uint8_t prev_portD = portD;

int ledState = 0;
int prev_ledState = ledState;

uint8_t group2leds = 0x0;
uint8_t group3leds = 0x0;
uint8_t group4leds = 0x0;

void serialEvent() {
  uint8_t buf[3];
  if(Serial.available()) {
    int rcvd = Serial.readBytes(buf,3);
    if(rcvd != 3) return;    
    switch(buf[0]) {
      case KEY: {
          uint8_t* leds = NULL;
          switch(buf[1]) {
            case 0x02:
              leds = &group2leds;
            break;
            case 0x03:
              leds = &group3leds;
            break;
            case 0x04:
              leds = &group4leds;
            break;
            default:
            break;
          }
          if(leds != NULL) *leds = buf[2];
      }
      break;
      case BANK: {
        if(buf[1] == BANK_LED[0] &&
           buf[2] == BANK_LED[1])
        {
          currentBank = CB_LEDS;
        } else
        if(buf[1] == BANK_CC[0] &&
           buf[2] == BANK_CC[1])
        {
          currentBank = CB_CC;
          Serial.write(BANK);
          Serial.write(BANK_CC,2);
        } else
        if(buf[1] == BANK_MT[0] &&
           buf[2] == BANK_MT[1])
        {
          currentBank = CB_MT;
        }
      }
      break;
      default:
      break;
    }
  }
}

void update() {
  Serial.write(BANK);
  Serial.write(BANK_CC,2);
  Serial.write(BANK);
  Serial.write(BANK_MT,2);
  Serial.write(POWER_ON,3);  
}

struct Encoder {
  int8_t m_value;
  uint8_t m_id;
  uint8_t m_pinA;
  uint8_t m_pinB;
};

#define ENCODER_COUNT (4)

Encoder encoders[ENCODER_COUNT] = {
  { .m_value = 0, .m_id = ENCODER_CONTRAST, .m_pinA = CONTRAST_A, .m_pinB = CONTRAST_B  },
  { .m_value = 0, .m_id = ENCODER_BRIGHT,   .m_pinA = BRIGHT_A,   .m_pinB = BRIGHT_B    },
  { .m_value = 0, .m_id = ENCODER_CHROMA,   .m_pinA = CHROMA_A,   .m_pinB = CHROMA_B    },
  { .m_value = 0, .m_id = ENCODER_PHASE,    .m_pinA = PHASE_A,    .m_pinB = PHASE_B     }
};

void rotaryEncoderChanged(void* encoder, bool pinstate) {
  Encoder* e = (Encoder*)encoder;
  bool pinB = digitalRead(e->m_pinB);
  unsigned long ms = millis();

  if(pinB != pinstate) 
  {    
    ++(e->m_value);
  } else if(pinB == pinstate) {
    --(e->m_value);
  }
}

unsigned long nextEncoderCheck_ms = 0;

void reportEncoder(uint8_t encoder, int8_t value) {
  int8_t ticks = 0;
  if(value < 0) {
    if(value >= -3) {
      ticks = -1;
    } else {
      ticks = -127;
    }
  } else {
    if(value <= 3) {
      ticks = 1; 
    } else {
      ticks = 127;
    }
  }
  if(currentBank != CB_ENCODERS) {
    Serial.write(BANK);
    Serial.write(BANK_ENCODER,2);
    currentBank = CB_ENCODERS;
  }
  Serial.write(KEY);
  Serial.write(encoder);
  Serial.write(ticks);   
}

void checkEncoders() {
  for(int j = 0; j < ENCODER_COUNT; ++j) {
    Encoder& e = encoders[j];
    if(e.m_value != 0) {
      reportEncoder(e.m_id,e.m_value);
      e.m_value = 0;
    }
  }
}

void setup() {
  Serial.begin(38400);
  pinMode(GPIO_RESET, OUTPUT);
  pinMode(UART_RTS, OUTPUT);
  pinMode(UART_CTS, OUTPUT);
  
  pinMode(MENU_IN, INPUT);
  pinMode(ENTER_IN, INPUT);
  pinMode(UP_IN, INPUT);
  pinMode(DOWN_IN, INPUT);
  
  digitalWrite(GPIO_RESET, HIGH);
  digitalWrite(UART_RTS, HIGH);
  digitalWrite(UART_CTS, LOW);
  delay(100);
 
  for(int j = 0; j < ENCODER_COUNT; ++j) {
    Encoder& e = encoders[j];
    pinMode(e.m_pinA, INPUT);
    pinMode(e.m_pinB, INPUT);
    PcInt::attachInterrupt(e.m_pinA, rotaryEncoderChanged, (void*)&e, CHANGE);
  }

  mcp23s17_u10.begin();
  mcp23s17_u10.pinMode   (0B0000000000000000);
  mcp23s17_u10.pullupMode(0B0000000000000000);

  mcp23s17_u11.begin();
  mcp23s17_u11.pinMode   (0B1111110011001111);
  mcp23s17_u11.pullupMode(0B0000001100110000);

  mcp23s17_u12.begin();
  mcp23s17_u12.pinMode   (0B1111111111111111);
  mcp23s17_u12.pullupMode(0B0000000000000000);
  
  prev_U11 = mcp23s17_u11.digitalRead();
  prev_U12 = mcp23s17_u12.digitalRead();
  // "Flush" any garbage
  while (Serial.available()) Serial.read();
  update();
}

#define pressedU11(k) ((U11 & k) && !(prev_U11 & k))
#define pressedU12(k) ((U12 & k) && !(prev_U12 & k))
#define pressedPortD(k) ((portD & k) && !(prev_portD & k))

void pushButton(Button_t& b) {
  if(currentBank != CB_SWITCHES) {
    Serial.write(BANK);
    Serial.write(BANK_SWITCH,2);
    currentBank = CB_SWITCHES;
  }
  Serial.write(KEY);
  Serial.write(b.group);
  Serial.write(b.id);          
};

void updateLEDStates() {
  if(group2leds & B_PHASE_MANUAL.id) {
    ledState |= LED_PHASE_MANUAL;
  } else {
    ledState &= ~LED_PHASE_MANUAL;
  }

  if(group2leds & B_CHROMA_MANUAL.id) {
    ledState |= LED_CHROMA_MANUAL;
  } else {
    ledState &= ~LED_CHROMA_MANUAL;
  }

  if(group2leds & B_BRIGHT_MANUAL.id) {
    ledState |= LED_BRIGHT_MANUAL;
  } else {
    ledState &= ~LED_BRIGHT_MANUAL;
  }

  if(group2leds & B_CONTRAST_MANUAL.id) {
    ledState |= LED_CONTRAST_MANUAL;
  } else {
    ledState &= ~LED_CONTRAST_MANUAL;
  }

  if(group3leds & B_SHIFT.id) {
    ledState |= LED_SHIFT;
  } else {
    ledState &= ~LED_SHIFT;
  }

  if(group3leds & B_UNDERSCAN_16_9.id) {
    ledState |= LED_UNDERSCAN_16_9;
  } else {
    ledState &= ~LED_UNDERSCAN_16_9;
  }

  if(group3leds & B_HORIZ_SYNC.id) {
    ledState |= LED_HORIZ_SYNC;
  } else {
    ledState &= ~LED_HORIZ_SYNC;
  }

  if(group3leds & B_VERT_BLUE_ONLY.id) {
    ledState |= LED_VERT_BLUE_ONLY;
  } else {
    ledState &= ~LED_VERT_BLUE_ONLY;
  }

  if(group3leds & B_MONO_R.id) {
    ledState |= LED_MONO_R;
  } else {
    ledState &= ~LED_MONO_R;
  }

  if(group4leds & B_APT_G.id) {
    ledState |= LED_APT_G;
  } else {
    ledState &= ~LED_APT_G;
  }

  if(group4leds & B_COMB_B.id) {
    ledState |= LED_COMB_B;
  } else {
    ledState &= ~LED_COMB_B;
  }

  if(group4leds & B_F1_F3.id) {
    ledState |= LED_F1_F3;
  } else {
    ledState &= ~LED_F1_F3;
  }

  if(group4leds & B_F2_F4.id) {
    ledState |= LED_F2_F4;
  } else {
    ledState &= ~LED_F2_F4;
  }

  if(group4leds & B_SAFE_AREA_ADDR.id) {
    ledState |= LED_ADDR_SAFE_AREA;
  } else {
    ledState &= ~LED_ADDR_SAFE_AREA;
  }
}

void loop() {
  U11 = mcp23s17_u11.digitalRead();
  U12 = mcp23s17_u12.digitalRead();
  portD = PIND;

  if(pressedPortD(0x80))          pushButton(B_DOWN);             else
  if(pressedPortD(0x40))          pushButton(B_ENTER);            else
  if(pressedPortD(0x10))          pushButton(B_UP);               else
  if(pressedPortD(0x20))          pushButton(B_MENU);

  if(pressedU11(POWER))           pushButton(B_POWER);            else 
  if(pressedU11(DEGAUSS))         pushButton(B_DEGAUSS);          else
  if(pressedU11(CONTRAST_MANUAL)) pushButton(B_CONTRAST_MANUAL);  else
  if(pressedU11(BRIGHT_MANUAL))   pushButton(B_BRIGHT_MANUAL);    else
  if(pressedU11(CHROMA_MANUAL))   pushButton(B_CHROMA_MANUAL);    else
  if(pressedU11(PHASE_MANUAL))    pushButton(B_PHASE_MANUAL);     else
  if(pressedU11(ADDR_SAFE_AREA))  pushButton(B_SAFE_AREA_ADDR);   else
  if(pressedU11(F1_F3))           pushButton(B_F1_F3);            else
  if(pressedU11(F2_F4))           pushButton(B_F2_F4);            else
  if(pressedU11(COMB_B))          pushButton(B_COMB_B);           else
  if(pressedU11(APT_G))           pushButton(B_APT_G);            else
  if(pressedU11(MONO_R))          pushButton(B_MONO_R);           else

  if(pressedU12(SHIFT))           pushButton(B_SHIFT);            else 
  if(pressedU12(UNDERSCAN_16_9))  pushButton(B_UNDERSCAN_16_9);   else
  if(pressedU12(HORIZ_SYNC))      pushButton(B_HORIZ_SYNC);       else
  if(pressedU12(VERT_BLUE_ONLY))  pushButton(B_VERT_BLUE_ONLY);   else
  if(pressedU12(KEY0))            pushButton(B_KEY_0);            else
  if(pressedU12(KEY1))            pushButton(B_KEY_1);            else
  if(pressedU12(KEY2))            pushButton(B_KEY_2);            else
  if(pressedU12(KEY3))            pushButton(B_KEY_3);            else
  if(pressedU12(KEY4))            pushButton(B_KEY_4);            else
  if(pressedU12(KEY5))            pushButton(B_KEY_5);            else
  if(pressedU12(KEY6))            pushButton(B_KEY_6);            else
  if(pressedU12(KEY7))            pushButton(B_KEY_7);            else
  if(pressedU12(KEY8))            pushButton(B_KEY_8);            else
  if(pressedU12(KEY9))            pushButton(B_KEY_9);            else
  if(pressedU12(KEY_DEL))         pushButton(B_KEY_DEL);          else
  if(pressedU12(KEY_ENTER))       pushButton(B_KEY_ENT);

  updateLEDStates();
  if(ledState != prev_ledState) {
    mcp23s17_u10.digitalWrite(ledState);
    prev_ledState = ledState;
  }

  if(millis() >= nextEncoderCheck_ms) {
    checkEncoders();
    nextEncoderCheck_ms += ENCODER_UPDATE_DELTA_MS;
  }
  
  prev_U11 = U11;
  prev_U12 = U12;
  prev_portD = portD;
}

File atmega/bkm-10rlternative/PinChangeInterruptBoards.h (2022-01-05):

/*
 * This file is derived from NicoHood's PinChangeInterrupt Library
 * https://github.com/NicoHood/PinChangeInterrupt
 */

/*
 * Edited to work with Atmega328PB, 2022, Martin Hejnfelt (martin@hejnfelt.com)
 */

// include guard
#pragma once

//================================================================================
// Board Definitions
//================================================================================

// Microcontroller specific definitions

#if defined(__AVR_ATmega328__) || defined(__AVR_ATmega328P__) || defined(__AVR_ATmega168__) || defined(__AVR_ATmega88__)
// Arduino Uno
#define PCINT_INPUT_PORT0 PINB
#define PCINT_INPUT_PORT1 PINC
#define PCINT_INPUT_PORT2 PIND

#elif defined(__AVR_ATmega328PB__)
#define PCINT_INPUT_PORT0 PINB
#define PCINT_INPUT_PORT1 PINC
#define PCINT_INPUT_PORT2 PIND
#define PCINT_INPUT_PORT3 PINE

#elif defined(__AVR_ATmega2560__) || defined(__AVR_ATmega1280__) || defined(__AVR_ATmega640__)
// Arduino Mega/Mega2560
// special Port1 case, pins are on 2 HW Pin Ports (E,J)
#define PCINT_INPUT_PORT0 PINB
#define PCINT_INPUT_PORT2 PINK
#define PCINT_INPUT_PORT1 ((PINE & 0x01) | (PINJ << 1))

#elif defined(__AVR_ATmega32U4__) || defined(__AVR_ATmega16U4__)
// Arduino Leonardo/Micro
#define PCINT_INPUT_PORT0 PINB

#elif defined(__AVR_AT90USB82__) || defined(__AVR_AT90USB162__) || defined(__AVR_ATmega32U2__) || defined(__AVR_ATmega16U2__) || defined(__AVR_ATmega8U2__)
// u2 Series/HoodLoader2
// u2 Series has crappy pin mappings for port 1
#define PCINT_INPUT_PORT0 PINB
#define PCINT_INPUT_PORT1 (((PINC >> 6) & (1 << 0)) | ((PINC >> 4) & (1 << 1)) | ((PINC >> 2) & (1 << 2)) | ((PINC << 1) & (1 << 3)) | ((PIND >> 1) & (1 << 4)))

#elif defined(__AVR_ATtiny25__) || defined(__AVR_ATtiny45__) || defined(__AVR_ATtiny85__)
// Attiny x5
#define PCINT_INPUT_PORT0 PINB

#elif defined(__AVR_ATtiny13__)
// Attiny 13A
#define PCINT_INPUT_PORT0 PINB

#elif defined(__AVR_ATtiny24__) || defined(__AVR_ATtiny44__) || defined(__AVR_ATtiny84__)
// Attiny x4
#define PCINT_INPUT_PORT0 PINA
#define PCINT_INPUT_PORT1 PINB

#elif defined(__AVR_ATmega1284P__) || defined(__AVR_ATmega644P__)
// 1284p and 644p, special 4 port case
#define PCINT_INPUT_PORT0 PINA
#define PCINT_INPUT_PORT1 PINB
#define PCINT_INPUT_PORT2 PINC
#define PCINT_INPUT_PORT3 PIND

#elif defined(__AVR_ATtinyX41__) || defined(__AVR_ATtiny441__) || defined(__AVR_ATtiny841__)
// Attiny x41
#define PCINT_INPUT_PORT0 PINA
#define PCINT_INPUT_PORT1 PINB

#else // Microcontroller not supported
#error PinChangeInterrupt library does not support this MCU.
#endif

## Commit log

2021-11-04 Initial PCB routed
    [adj-knobs.sch, bkm-10rlternative.kicad_pcb, bkm-10rlternative.sch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]
2021-11-05 Added texts, fixed pullups
    [bkm-10rlternative.kicad_pcb, function-buttons.sch, mcu-rs485.sch]
2021-11-05 Minor changes
    [bkm-10rlternative.kicad_pcb, mcu-rs485.sch]
2021-12-13 A bunch of changes, full duplex 422
    [adj-knobs.sch, bkm-10rlternative.kicad_pcb, function-buttons.sch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]
2022-01-05 Fixed switch footprints and encoder resistors
    [adj-knobs.sch, bkm-10rlternative.kicad_pcb, mcu-rs485.sch]
2022-01-08 3D files and minor stuff
    [TL1240xQ2Jxxx.stp, adj-knobs.sch, bkm-10rlternative.kicad_pcb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]
2022-01-08 Updated readme with serial cable info
